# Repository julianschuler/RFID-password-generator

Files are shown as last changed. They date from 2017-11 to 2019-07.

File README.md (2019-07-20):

# RFID password generator
#### Note: This project is just for reference and won't be continued, a similar approach without the RFID interface can be found in the more recent [USB password manager project](https://github.com/julianschuler/USB-password-manager). The reason for the discontination of this project is the minuscule added security in comparison to the extra effort of using a RFID interface for authentification. Furthermore a password manager is an easier and more secure way of generating and storing cryptographically strong passwords, see the [security evaluations section](https://github.com/julianschuler/USB-password-manager#Security-evaluations) of the USB password manager project.

## Introduction
The RFID password generator is a simple way to generate cryptographic passwords and save them in hardware, only accessable with the right RFID tag.

Using it is as simple as plugging it into a USB port and hold a previously registered RFID tag above, the RFID password generator will type your password. Each RFID tag refers to one password, to add a RFID tag or change the password of a registered one, press the button while holding the RFID tag above it or hit Caps Lock four times before, in both cases a new random password will be generated.

## Variants
This project has two versions, a flat and a normal version. The main difference is the form (the flat version has the dimensions of a credit card and fits perfectly inside your wallet), due to its thickness of just 2.4mm the flat version doesn't include a button for adding and changing passwords, you have to hit Caps Lock four times to do this.

Keep in mind that the flat version is a lot more complicated to build compared to the normal version due to its tiny SMD parts. Nevertheless, you should have at least experience in SMD soldering and Arduino/ATtiny programming, this isn't a beginner project!

## Build Instructions
If you want to rebuild this project, see [Build Instructions](documentation/build-instructions.md).

## Licenses
All files of this project except the pcb and schematic files are licensed under MIT License (see [`LICENSE.txt`](LICENSE.txt) for further information). These pcb and schematic files are licensed under [Creative Commons Attribution Share Alike 4.0](https://creativecommons.org/licenses/by-sa/4.0/).

## To do
- add connection diagrams
- create PCB files for the flat version
- create a parts list for the normal version

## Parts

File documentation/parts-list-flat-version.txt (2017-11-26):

This is a parts list for the RFID password generator

Direct links to the components:

1x ATTINY84A-10MU (Attiny84A in QFN package, main µC):
https://www.mouser.com/ProductDetail/Microchip-Technology-Atmel/ATTINY84A-MU/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

1x MFRC52202HN1,151 (13.56MHz RFID reader IC):
https://www.mouser.com/ProductDetail/NXP-Semiconductors/MFRC52202HN1151/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

1x LD39100PUR (adjustable LDO voltage regulator):
https://www.mouser.com/ProductDetail/STMicroelectronics/LD39100PUR/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

1x CX3225SB12000H0PSTC1 (12Mhz SMD crystal for the Attiny):
https://www.mouser.com/ProductDetail/AVX-Kyocera/CX3225SB12000H0PSTC1/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

1x XRCGB27M120F0Z00R0 (27.12MHz SMD crystal for the RFID reader IC):
https://www.mouser.com/ProductDetail/Murata-Electronics/XRCGB27M120F0Z00R0/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

1x 885012106010 (1µF SMD capacitor):
https://www.mouser.de/ProductDetail/Wurth-Electronics/885012106010/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

2x CS160808-R56K (560nH SMD inductor):
https://www.mouser.de/ProductDetail/Bourns/CS160808-R56K/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

2x UHD1110-FKA-CL1A13r3q1BBQFMF3 (RGB SMD LED):
https://www.mouser.de/ProductDetail/Cree-Inc/UHD1110-FKA-CL1A13r3q1BBQFMF3/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

Complete BOM for copying & pasting it to https://www.mouser.com/bom (you have to be logged in)

ATTINY84A-10MU|1
MFRC52202HN1,151|1
LD3900PUR|1
CX3225SB12000H0PSTC1|1
XRCGB27M120F0Z00R0|1

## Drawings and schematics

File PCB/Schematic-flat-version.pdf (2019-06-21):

3.6V
3.6V

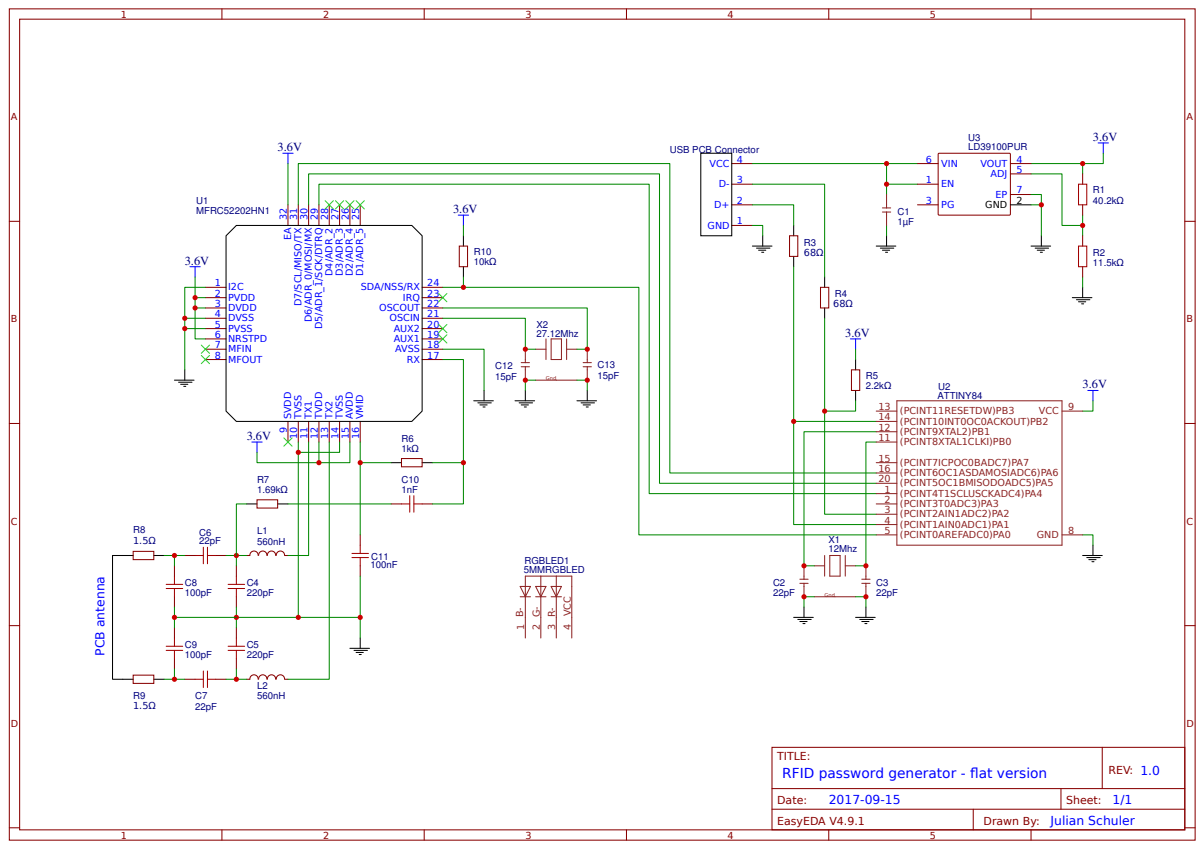
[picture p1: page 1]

RX 17 AVSS 18 AUX1 19 AUX2 20 OSCIN 21 OSCOUT 22 IRQ 23 SDA/NSS/RX 24 D¹/ADR_5 25 D²/ADR_4 26 D³/ADR_3 27 D⁴/ADR_2 28 D⁵/ADR_1/SCK/DTRQ ²⁹ D⁶/ADR_0/MOSI/MX 30 D⁷/SCL/MISO/TX 31 EA 32

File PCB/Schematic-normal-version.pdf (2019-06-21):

3.6V

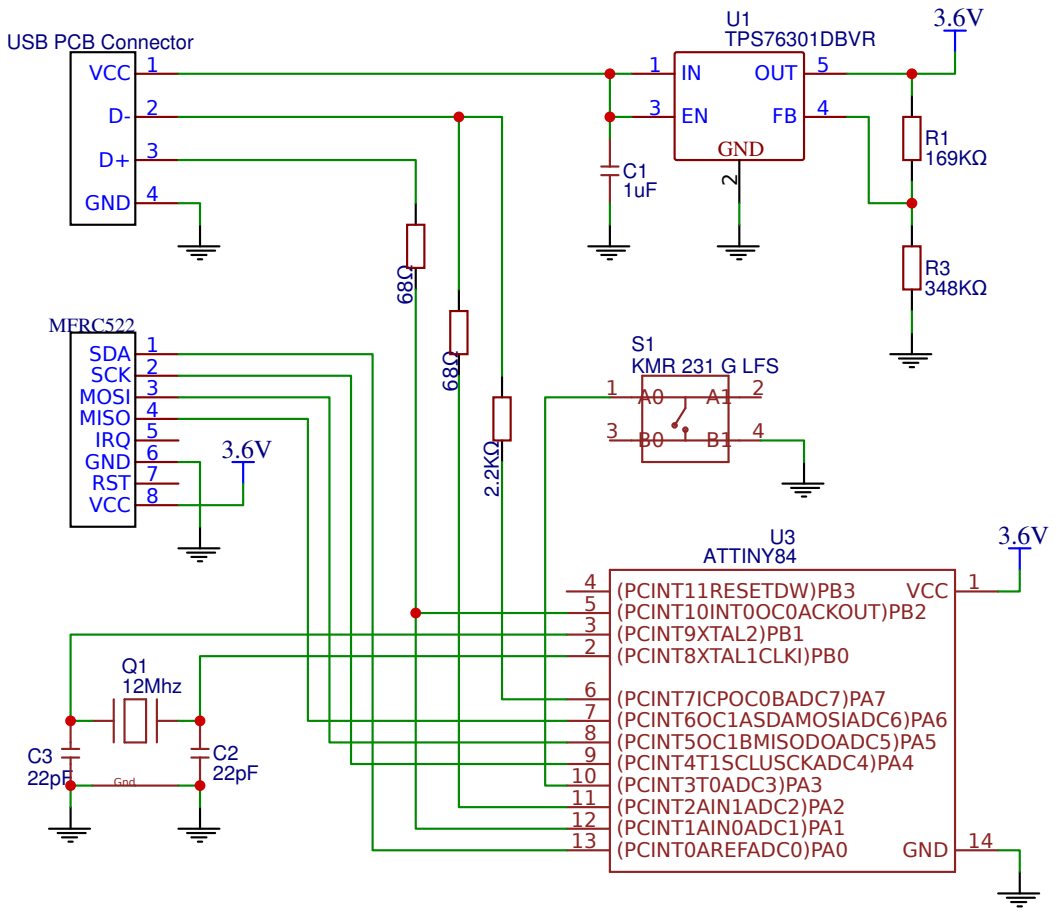
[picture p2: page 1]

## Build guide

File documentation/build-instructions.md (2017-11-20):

# Build Instructions
## Additional components required
### Hardware
- AVR programmer (in this tutorial an Arduino is used [as ISP](https://www.arduino.cc/en/Tutorial/ArduinoISP), using another programmer should be a similar procedure)
- soldering iron, solder
- for programming the ATtiny: jumper cables, 10µF capacitor (just for the Arduino as ISP)
- for the flat version: at least a hot air gun, ideally a hot air soldering station
- optional: flux (highly recommended for the flat version)

### Software
- [Arduino IDE](https://www.arduino.cc/en/main/software) (use 1.6.4+, older Versions may not work)
- [USBKeyboard library](https://github.com/julianschuler/USBKeyboard)
- avrdude (the easiest way to install it under Windows is installing [WinAVR](https://www.sourceforge.net/projects/winavr/))

## Assembly
### Normal version
Get yourself all parts listed in [`parts-list-normal-version.txt`](parts-list-normal-version.txt) and solder them to the pcb, starting with the SMDs. **Do not solder the ATtiny directly to the pcb, use the socket instead!** 

### Flat version
Solder all parts listed in [`parts-list-flat-version.txt`](parts-list-flat-version.txt) to the main pcb. For soldering the QFN parts it is recommended to add a tiny amount of solder on the pcb pads, apply a lot of flux around them and position the parts. Heat the parts one by one with hot air until the solder starts flowing, after that the parts should align themselves. **Be careful not to heat the parts to long, otherwise you can damage them!**

## Programming the ATtiny84A
If you have no AVR programmer, set up your Arduino [as ISP](https://www.arduino.cc/en/Tutorial/ArduinoISP) and connect it to the ATtiny as shown below.

[need to add connection diagrams here]

Copy the [USBKeyboard library](https://github.com/julianschuler/USBKeyboard) into your Arduino libraries folder, which can normally be found under Documents/Arduino/libraries

Open the sketch [`rfid-password-generator-normal-version.ino`](../sourcecode/RFID-password-generator-normal-version/RFID-password-generator-normal-version.ino) respectively [`rfid-password-generator-flat-version.ino`](../sourcecode/RFID-password-generator-flat-version/RFID-password-generator-flat-version.ino) with the Arduino IDE and open _File > Preferences_. Paste `http://drazzy.com/package_drazzy.com_index.json` into the _Additional Boards manager URLs_ field near the bottum and click _OK_. To install the ATtiny Core open _Tools > Board > Boards Manager_. Scroll to the bottom, select _ATTinyCore by Spence Konde_ and click on the _Install_ button.

Go to _Tools_ and select `Board: "ATtiny24/44/84"`, `B.O.D.: "B.O.D. Disabled"`, `LTO (1.6.11+ only): "Enabled"`, `Pin Mapping: "Counterclockwise (like ATTinyCore)"`, `Clock: "12 MHz (external)"`, `Chip "ATtiny84"`, `Port: "COMx"` (`COMx` ist your Arduino port, e. g. `COM3`), `Programmer: "Arduino as ISP"`.
Compile and flash the sketch by clicking on the upload button.

Press `Win+R`, type in `cmd` and hit Enter to run the command prompt. Paste `avrdude -c arduino -p t84 -p COMx -b 19200 -U lock:w:0xfc:m` in and change `COMx` to your Arduino port, e. g. `COM3`. By running the command you lock your ATtiny, this way the flash and especially the EEPROM, where your passwords are stored, are unaccessable from the outside.
The ATtiny is still reprogrammable, but the EEPROM content gets lost by doing this.

Plug the ATtiny into the socket respectively disconnect the Arduino/AVR programmer from the programming header. Add an unused  RFID tag by holding it above the RFID password generator plugged into an USB port while pressing the button or after hitting Caps Lock four times, this tag will be set as your master tag. By repeating this procedure with the master tag, all saved RFID tags and their corresponding passwords will be deleted.

In the current configuration ten RFID tags (+ master tag) and therefore ten passwords with 46 colums each can be saved, it can be adjusted by changing `#define passwordLength` to the desired value. The number of RFID tags in relation on the password length can be calculated by `507/(password length + 4)`.

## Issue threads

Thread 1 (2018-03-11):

More info on flat pcb design

tERB00, 2018-03-11:
Hi! Found your project on Github - looks very interesting to me!
According to BOM of your flat pcb design it is much simpler than the regular RC522 board - only crystal, one cap and two inductors.
I am curious how good that reader works? Because regular RC522 boards having hard time reading 7-byte UID cards at 3.3v - they work only on 5v, which is not good for the chip itself...
Also do you have any blog or website where I can find more info on your project?
Thanks!

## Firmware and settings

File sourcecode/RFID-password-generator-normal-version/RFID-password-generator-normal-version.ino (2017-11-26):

#include <USBKeyboard.h>
#include <EEPROM.h>
#include <avr/wdt.h>


#define printInformation				1 // set this to 1 to enable feedback for e. g. changing passwords
#define Debug							0 // set this to 1 to enable Debug
#define useWDT							0 // set this to 1 to enable the watch dog timer

#define EN								0
#define DE								1

#define Language						DE // EN for English, DE for German
#define maxPasswords					10 // set this to the required password count, 10 passwords equals 46 characters per password, more passwords equals less characters

#if (Language == EN)
	#define Layout						LAYOUT_US
	#define MasterTagNotSetMsg			"Note: The master tag isn't set yet, press the button while holding a RFID tag above the reader to set this tag as master tag."
	#define SetMasterTagMsg				"The master tag was set."
	#define DeletedAllDataMsg			"All data has been deleted."
	#define PressButtonMsg				"To delete all data, press the button and hold the master tag above the reader again."
	#define ChangePasswordMsg1			"Changed password for RFID tag #"
	#define ChangePasswordMsg2			'.'
	#define AddRFIDTagMsg1				"Added new RFID tag as RFID tag #"
	#define AddRFIDTagMsg2				'.'
#elif (Language == DE)
	#define Layout						LAYOUT_DE
	#define MasterTagNotSetMsg			"Hinweis: Der Master-Tag wurde noch nicht festgelegt, druecke den Taster und halte waehrenddessen einen RFID-Tag ueber den Leser, um diesen als Master-Tag zu verwenden."
	#define SetMasterTagMsg				"Der Master-Tag wurde festgelegt."
	#define DeletedAllDataMsg			"Alle Daten wurden geloescht."
	#define PressButtonMsg				"Um alle Daten zu loeschen, druecke den Taster und halte den Master-Tag erneut ueber den Leser."
	#define ChangePasswordMsg1			"Das Passwort fuer RFID-Tag #"
	#define ChangePasswordMsg2			" wurde geaendert."
	#define AddRFIDTagMsg1				"Ein neuer RFID-Tag wurde als RFID-Tag #"
	#define AddRFIDTagMsg2				" hinzugefuegt."
#endif


#if defined(__AVR_ATtiny25__) || defined(__AVR_ATtiny45__) || defined(__AVR_ATtiny85__) || defined(__AVR_ATtiny24__) || defined(__AVR_ATtiny44__) || defined(__AVR_ATtiny84__) || defined(__AVR_ATtiny2313__) || defined(__AVR_ATtiny4313__)
	#include <SoftwareSerial.h>
	
	#define TINY_SPI
	#define SPI_begin()					TinySPI_begin()
	#define SPI_transfer(b)				TinySPI_transfer(b)
	#define SPI_beginTransaction(s)
	#define SPI_endTransaction()
	
	#define ButtonpinPort					A
	#define ButtonpinBit					3
	
	#if defined(__AVR_ATtiny25__) || defined(__AVR_ATtiny45__) || defined(__AVR_ATtiny85__)
		#define SPIPort					A
		#define CS						3
		#define DI						0
		#define DO						1
		#define USCK					2
		#define TX						4
	#elif defined(__AVR_ATtiny24__) || defined(__AVR_ATtiny44__) || defined(__AVR_ATtiny84__)
		#define SPIPort					A
		#define CS						0
		#define DI						6
		#define DO						5
		#define USCK					4
		#define TX						7
	#elif defined(__AVR_ATtiny2313__) || defined(__AVR_ATtiny4313__)
		#define SPIPort					B
		#define CS						4
		#define DI						5
		#define DO						6
		#define USCK					7
		#define TX						3
	#endif
	
	#if Debug
		// connect D3 to the RX pin of an UART interface (e. g. an Arduino with Reset connected to GND), leave TX not connected
		SoftwareSerial mSerial(255, TX);
		#define usbDeviceConnect()
		#define usbDeviceDisconnect()
	#endif
#else
	#include <SPI.h>
	
	#define SPI_begin()					SPI.begin()
	#define SPI_transfer(b)				SPI.transfer(b)
	#define SPI_beginTransaction(s)		SPI.beginTransaction(s)
	#define SPI_endTransaction()		SPI.endTransaction()
	#define mSerial						Serial
	
	#define SPIPort						B
	#define CS							1
	#define ButtonpinPort					D
	#define ButtonpinBit					5
	
	SPISettings spiSettings = SPISettings(SPI_CLOCK_DIV4, MSBFIRST, SPI_MODE0);
#endif

#define conc(a, b)						(a ## b)
#define concat(a, b)					conc(a, b) //double define allows concatenante strings defined by macros

#define directRead(port, bit)			(concat(PIN, port) >> bit & 1)
#define directMode(port, bit, mode)		(mode) ? concat(DDR, port) |= 1 << bit : concat(DDR, port) &= ~(1 << bit)
#define directWrite(port, bit, state)	(state) ? concat(PORT, port) |= 1 << bit : concat(PORT, port) &= ~(1 << bit)

#define RFIDTagLength					4
#define EEPROMSize						512
#define passwordLength					(EEPROMSize-1-RFIDTagLength) / maxPasswords - RFIDTagLength

#define PICC_CMD_REQA					0x26
#define PICC_CMD_HLTA					0x50
#define PICC_CMD_CT						0x88
#define PICC_CMD_SEL_CL1				0x93

#define PCD_Idle						0x00
#define PCD_CalcCRC						0x03
#define PCD_Transceive					0x0C
#define PCD_SoftReset					0x0F

#define CommandReg						0x01 << 1
#define ComIrqReg						0x04 << 1
#define DivIrqReg						0x05 << 1
#define ErrorReg						0x06 << 1
#define FIFODataReg						0x09 << 1
#define FIFOLevelReg					0x0A << 1
#define ControlReg						0x0C << 1
#define BitFramingReg					0x0D << 1
#define CollReg							0x0E << 1
#define ModeReg							0x11 << 1
#define TxModeReg						0x12 << 1
#define RxModeReg						0x13 << 1
#define TxControlReg					0x14 << 1
#define TxASKReg						0x15 << 1
#define CRCResultRegH					0x21 << 1
#define CRCResultRegL					0x22 << 1
#define ModWidthReg						0x24 << 1
#define TModeReg						0x2A << 1
#define TPrescalerReg					0x2B << 1
#define TReloadRegH						0x2C << 1
#define TReloadRegL						0x2D << 1


USBKeyboard mKeyboard = USBKeyboard(Layout);

const uint32_t randomKey = 987256;

uint8_t RFIDTagMaster[RFIDTagLength];
uint8_t passwordCount;

uint8_t uid[4];


void setup() {
	TIMSK0 = 0;
	directMode(ButtonpinPort, ButtonpinBit, INPUT);
	directWrite(ButtonpinPort, ButtonpinBit, HIGH);
	randomSeed(randomKey);
	passwordCount = EEPROM.read(0);
	if (passwordCount != 255) {
		for (uint8_t i = 0; i < RFIDTagLength; i++) {
			RFIDTagMaster[i] = EEPROM.read(i + 1);
		}
	}
	#if printInformation
	else {
		mKeyboard.println(F(MasterTagNotSetMsg));
	}
	#endif
	SPI_begin();
	PCD_Init();
	#if Debug
	mSerial.begin(9600);
	#endif
	#if useWDT
	wdt_enable(WDTO_60MS);
	#endif
}


void loop() {
	if (PICC_IsNewCardPresent() && PICC_ReadCardSerial()) {
		PICC_HaltA();
		#if Debug
		mSerial.print("Found new tag: ");
		for (uint8_t i = 0; i < 4; i++) {
			mSerial.print(uid[i], HEX);
			mSerial.print(' ');
		}
		mSerial.println();
		#endif
		if (passwordCount == 255) {
			if (directRead(ButtonpinPort, ButtonpinBit) == LOW) {
				passwordCount = 0;
				#if Debug
				mSerial.println("Set master tag");
				#endif
				EEPROM.write(0, passwordCount);
				for (uint8_t i = 0; i < RFIDTagLength; i++) {
					RFIDTagMaster[i] = uid[i];
					EEPROM.write(i + 1, RFIDTagMaster[i]);
					#if useWDT
					wdt_reset();
					#endif
				}
				#if printInformation
				mKeyboard.println(F(SetMasterTagMsg));
				#endif
			}
		}
		else {
			bool knownRFIDTag = false;
			for (uint8_t i = 0; i < RFIDTagLength && !knownRFIDTag; i++) {
				knownRFIDTag = true;
				if (uid[i] != RFIDTagMaster[i]) {
					knownRFIDTag = false;
				}
			}
			if (knownRFIDTag) {
				if (directRead(ButtonpinPort, ButtonpinBit) == LOW) {
					for (uint16_t i = RFIDTagLength + 1; i < EEPROMSize; i++) {
						EEPROM.write(i, 255);
					}
					EEPROM.write(0, 255);
					#if printInformation
					mKeyboard.println(F(DeletedAllDataMsg));
					#endif
				}
				#if printInformation
				else {
					mKeyboard.println(F(PressButtonMsg));
				}
				#endif
			}
			for (uint8_t i = 0; i < maxPasswords && !knownRFIDTag; i++) {
				knownRFIDTag = true;
				for (uint8_t j = 0; j < RFIDTagLength && knownRFIDTag; j++) {
					if (uid[j] != EEPROM.read(i * (passwordLength + RFIDTagLength) + j + RFIDTagLength + 1)) {
						knownRFIDTag = false;
					}
				}
				if (knownRFIDTag) {
					if (directRead(ButtonpinPort, ButtonpinBit) == LOW) {
						ChangePassword(i);
					}
					else {
						SendPassword(i);
					}
				}
			}
			
			if (!knownRFIDTag && directRead(ButtonpinPort, ButtonpinBit) == LOW) {
				AddRFIDTag();
			}
		}
		for (uint16_t i = 0; i < 255; i++) {
			mKeyboard.update();
			delayMicroseconds(20000);
			#if useWDT
			wdt_reset();
			#endif
		}
	}
	mKeyboard.update();
	delayMicroseconds(20000);
	#if useWDT
	wdt_reset();
	#endif
}


void SendPassword(uint8_t index) {
	uint8_t data;
	#if Debug
	mSerial.println("Sending password");
	#endif
	for (uint8_t i = 0; i < passwordLength; i++) {
		data = EEPROM.read(index * (passwordLength + RFIDTagLength) + i + 2*RFIDTagLength + 1);
		mKeyboard.sendKey(data % 36 + 4, (data / 36) * 2);
		#if useWDT
		wdt_reset();
		#endif
	}
}


void ChangePassword(uint8_t index) {
	uint8_t data;
	#if Debug
	mSerial.println("Changing password");
	#endif
	for (uint8_t i = 0; i < passwordLength; i++) {
		data = random(72);
		EEPROM.write(index * (passwordLength + RFIDTagLength) + i + 2*RFIDTagLength + 1, data);
		#if useWDT
		wdt_reset();
		#endif
	}
	#if printInformation
	mKeyboard.print(F(ChangePasswordMsg1));
	mKeyboard.print(index + 1);
	mKeyboard.println(F(ChangePasswordMsg2));
	#endif
}


void AddRFIDTag() {
	#if Debug
	mSerial.println("Adding RFID tag");
	#endif
	if (passwordCount < maxPasswords) {
		uint8_t data;
		for (uint8_t i = 0; i < RFIDTagLength; i++) {
			EEPROM.write(passwordCount * (passwordLength + RFIDTagLength) + i + RFIDTagLength + 1, uid[i]);
			#if useWDT
			wdt_reset();
			#endif
		}
		for (uint8_t i = 0; i < passwordLength; i++) {
			data = random(72);
			EEPROM.write(passwordCount * (passwordLength + RFIDTagLength) + i + 2*RFIDTagLength + 1, data);
			#if useWDT
			wdt_reset();
			#endif
		}
		passwordCount++;
		EEPROM.write(0, passwordCount);
	}
	#if printInformation
	mKeyboard.print(F(AddRFIDTagMsg1));
	mKeyboard.print(passwordCount);
	mKeyboard.println(F(AddRFIDTagMsg2));
	#endif
}


#ifdef TINY_SPI
void TinySPI_begin() {
	directMode(SPIPort, USCK, OUTPUT);
	directMode(SPIPort, DO, OUTPUT);
	directMode(SPIPort, DI, INPUT);
	USICR = _BV(USIWM0);
}


uint8_t TinySPI_transfer(uint8_t b) {
	USIDR = b;
	USISR = _BV(USIOIF);
	do
		USICR = _BV(USIWM0) | _BV(USICS1) | _BV(USICLK) | _BV(USITC);
	while ((USISR & _BV(USIOIF)) == 0);
	return USIDR;
}
#endif


void PCD_WriteRegister(uint8_t reg, uint8_t value) {
	SPI_beginTransaction(spiSettings);
	directWrite(SPIPort, CS, LOW);
	SPI_transfer(reg);
	SPI_transfer(value);
	directWrite(SPIPort, CS, HIGH);
	SPI_endTransaction();
}


void PCD_WriteRegister(uint8_t reg, uint8_t count, uint8_t *values) {
	SPI_beginTransaction(spiSettings);
	directWrite(SPIPort, CS, LOW);
	SPI_transfer(reg);
	for (uint8_t index = 0; index < count; index++) {
		SPI_transfer(values[index]);
	}
	directWrite(SPIPort, CS, HIGH);
	SPI_endTransaction();
}


uint8_t PCD_ReadRegister(uint8_t reg) {
	uint8_t value;
	SPI_beginTransaction(spiSettings);
	directWrite(SPIPort, CS, LOW);
	SPI_transfer(0x80 | reg);
	value = SPI_transfer(0);
	directWrite(SPIPort, CS, HIGH);
	SPI_endTransaction();
	return value;
}


void PCD_ReadRegister(uint8_t reg, uint8_t count, uint8_t *values, uint8_t rxAlign) {
	if (count == 0)
		return;
	uint8_t address = 0x80 | reg;
	uint8_t index = 0;
	SPI_beginTransaction(spiSettings);
	directWrite(SPIPort, CS, LOW);
	count--;
	SPI_transfer(address);
	if (rxAlign) {
		uint8_t mask = (0xFF << rxAlign) & 0xFF;
		uint8_t value = SPI_transfer(address);
		values[0] = (values[0] & ~mask) | (value & mask);
		index++;
	}
	while (index < count) {
		values[index] = SPI_transfer(address);
		index++;
	}
	values[index] = SPI_transfer(0);
	directWrite(SPIPort, CS, HIGH);
	SPI_endTransaction();
}


void PCD_Init() {
	directMode(SPIPort, CS, OUTPUT);
	directWrite(SPIPort, CS, HIGH);
	
	PCD_WriteRegister(CommandReg, PCD_SoftReset);
	delayMicroseconds(50000);
	while (PCD_ReadRegister(CommandReg) & 0x10) {}
	
	PCD_WriteRegister(TxModeReg, 0x00);
	PCD_WriteRegister(RxModeReg, 0x00);
	PCD_WriteRegister(ModWidthReg, 0x26);
	PCD_WriteRegister(TModeReg, 0x80);
	PCD_WriteRegister(TPrescalerReg, 0xA9);
	PCD_WriteRegister(TReloadRegH, 0x03);
	PCD_WriteRegister(TReloadRegL, 0xE8);
	PCD_WriteRegister(TxASKReg, 0x40);
	PCD_WriteRegister(ModeReg, 0x3D);
	
	uint8_t value = PCD_ReadRegister(TxControlReg);
	if ((value & 0x03) != 0x03)
		PCD_WriteRegister(TxControlReg, value | 0x03);
}


bool PCD_CalculateCRC(uint8_t *data, uint8_t length, uint8_t *result) {
	PCD_WriteRegister(CommandReg, PCD_Idle);
	PCD_WriteRegister(DivIrqReg, 0x04);
	PCD_WriteRegister(FIFOLevelReg, 0x80);
	PCD_WriteRegister(FIFODataReg, length, data);
	PCD_WriteRegister(CommandReg, PCD_CalcCRC);
	
	for (uint16_t i = 5000; i > 0; i--) {
		uint8_t n = PCD_ReadRegister(DivIrqReg);
		if (n & 0x04) {
			PCD_WriteRegister(CommandReg, PCD_Idle);
			result[0] = PCD_ReadRegister(CRCResultRegL);
			result[1] = PCD_ReadRegister(CRCResultRegH);
			return true;
		}
	}
	return false;
}


uint8_t PCD_CommunicateWithPICC(uint8_t *sendData, uint8_t sendLen, uint8_t *backData = nullptr, uint8_t *backLen = nullptr, uint8_t *validBits = nullptr, uint8_t rxAlign = 0) {
	uint8_t txLastBits = validBits ? *validBits : 0;
	uint8_t bitFraming = (rxAlign << 4) + txLastBits;
	
	PCD_WriteRegister(CommandReg, PCD_Idle);
	PCD_WriteRegister(ComIrqReg, 0x7F);
	PCD_WriteRegister(FIFOLevelReg, 0x80);
	PCD_WriteRegister(FIFODataReg, sendLen, sendData);
	PCD_WriteRegister(BitFramingReg, bitFraming);
	PCD_WriteRegister(CommandReg, PCD_Transceive);
	PCD_WriteRegister(BitFramingReg, PCD_ReadRegister(BitFramingReg) | 0x80);
	
	uint16_t i;
	for (i = 2000; i > 0; i--) {
		uint8_t n = PCD_ReadRegister(ComIrqReg);
		if (n & 0x30)
			break;
		if (n & 0x01)
			return 0;
	}
	
	if (i == 0)
		return 0;
	uint8_t errorRegValue = PCD_ReadRegister(ErrorReg);
	if (errorRegValue & 0x13)
		return 0;
	if (backData && backLen) {
		uint8_t n = PCD_ReadRegister(FIFOLevelReg);
		if (n > *backLen)
			return 0;
		*backLen = n;
		PCD_ReadRegister(FIFODataReg, n, backData, rxAlign);
		if (validBits)
			*validBits = PCD_ReadRegister(ControlReg) & 0x07;
	}
	
	if (errorRegValue & 0x08)
		return 2;
	return 1;
}


bool PICC_IsNewCardPresent() {
	uint8_t bufferATQA[2];
	uint8_t bufferSize = sizeof(bufferATQA);
	uint8_t validBits = 7;
	uint8_t cmd = PICC_CMD_REQA;
	
	PCD_WriteRegister(TxModeReg, 0x00);
	PCD_WriteRegister(RxModeReg, 0x00);
	PCD_WriteRegister(ModWidthReg, 0x26);
	PCD_WriteRegister(CollReg, PCD_ReadRegister(CollReg) & 0x7F);
	
	return PCD_CommunicateWithPICC(&cmd, 1, bufferATQA, &bufferSize, &validBits);
}


bool PICC_ReadCardSerial() {
	uint8_t validBits = 0;
	bool selectDone = false;
	bool useCascadeTag;
	uint8_t cascadeLevel = 1;
	uint8_t count;
	uint8_t index;
	uint8_t uidIndex;
	int8_t currentLevelKnownBits;
	uint8_t buffer[9];
	uint8_t bufferUsed;
	uint8_t rxAlign;
	uint8_t txLastBits;
	uint8_t *responseBuffer;
	uint8_t responseLength;
	
	PCD_WriteRegister(CollReg, PCD_ReadRegister(CollReg) & 0x7F);
	buffer[0] = PICC_CMD_SEL_CL1;
	uidIndex = 0;
	currentLevelKnownBits = validBits - (8 * uidIndex);
	if (currentLevelKnownBits < 0)
		currentLevelKnownBits = 0;
	index = 2;
	uint8_t bytesToCopy = currentLevelKnownBits / 8 + (currentLevelKnownBits % 8 ? 1 : 0);
	if (bytesToCopy) {
		if (bytesToCopy > 4)
			bytesToCopy = 4;
		for (count = 0; count < bytesToCopy; count++) {
			buffer[index++] = uid[uidIndex + count];
		}
	}
	while (!selectDone) {
		if (currentLevelKnownBits >= 32) {
			buffer[1] = 0x70;
			buffer[6] = buffer[2] ^ buffer[3] ^ buffer[4] ^ buffer[5];
			if (!PCD_CalculateCRC(buffer, 7, &buffer[7]))
				return false;
			txLastBits		= 0;
			bufferUsed		= 9;
			responseBuffer	= &buffer[6];
			responseLength	= 3;
		}
		else {
			txLastBits		= currentLevelKnownBits % 8;
			count			= currentLevelKnownBits / 8;
			index			= 2 + count;
			buffer[1]		= (index << 4) + txLastBits;
			bufferUsed		= index + (txLastBits ? 1 : 0);
			responseBuffer	= &buffer[index];
			responseLength	= sizeof(buffer) - index;
		}
		
		rxAlign = txLastBits;
		PCD_WriteRegister(BitFramingReg, (txLastBits << 4) + txLastBits);
		uint8_t result = PCD_CommunicateWithPICC(buffer, bufferUsed, responseBuffer, &responseLength, &txLastBits, rxAlign);
		if (result == 2) {
			uint8_t valueOfCollReg = PCD_ReadRegister(CollReg);
			if (valueOfCollReg & 0x20)
				return false;
			uint8_t collisionPos = valueOfCollReg & 0x1F;
			if (collisionPos == 0)
				collisionPos = 32;
			if (collisionPos <= currentLevelKnownBits)
				return false;
			currentLevelKnownBits = collisionPos;
			count			= (currentLevelKnownBits - 1) % 8;
			index			= 1 + (currentLevelKnownBits / 8) + (count ? 1 : 0);
			buffer[index]	|= (1 << count);
		}
		else if (result != 1) {
			return false;
		}
		else {
			if (currentLevelKnownBits >= 32)
				selectDone = true;
			else
				currentLevelKnownBits = 32;
		}
	}
	
	index		= (buffer[2] == PICC_CMD_CT) ? 3 : 2;
	bytesToCopy = (buffer[2] == PICC_CMD_CT) ? 3 : 4;
	for (count = 0; count < bytesToCopy; count++) {
		uid[uidIndex + count] = buffer[index++];
	}
	if (!PCD_CalculateCRC(responseBuffer, 1, &buffer[2]) || responseLength != 3 || txLastBits != 0)
		return false;
	return true;
}


bool PICC_HaltA() {
	uint8_t buffer[4] = {PICC_CMD_HLTA, 0, 0, 0};
	if (PCD_CalculateCRC(buffer, 2, &buffer[2]))
		return !PCD_CommunicateWithPICC(buffer, sizeof(buffer));
	return false;
}

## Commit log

2017-09-23 minor changes
    changed crystal label, fixed links
    [RFID-password-generator.fzz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]
2017-11-19 Major changes
    Removed MFRC522 library, switched to own USBKeyboard library, added Arduino UNO support for simpler debug and more
2017-11-19 Removed MFRC522 library
    [Arduino-Uno-r3-with-RFID-RC522.fzz]
2017-11-20 Adjusted pinout to pcb
2019-06-21 Add EasyEDA files, pack gerber files and rename files
    [Fritzing-alternative-normal-version.fzz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]
